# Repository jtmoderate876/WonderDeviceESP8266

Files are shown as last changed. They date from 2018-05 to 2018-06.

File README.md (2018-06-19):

# WonderDeviceESP8266

The device can be reset using #   DoubleResetDetect by Jens-Christian Skibakk

You can then configure via wifimanager by connecting to the ESPXXXXXX device and setting your SSID/PWD/ETC.

Raspberry pi's set up for Wonderware ITME "IoTView" per the following:

```
#install apache on pi:
sudo apt-get install apache2
#sudo systemctl disable apache2
#sudo systemctl stop apache2
#sudo systemctl restart apache2
sudo systemctl start apache2
sudo systemctl enable apache2
#skip the old service way which still works:
#sudo service apache2 start
#sudo service apache2 restart
#enable cgi
sudo a2enmod cgi
sudo cp /etc/apache2/mods-available/cgi.load /etc/apache2/mods-enabled/
```

Now from a windows pc that has Wonderware ITME installed copy the remote agent files from PC to removable drive:
copy "C:\Program Files (x86)\Wonderware\InTouch Machine Edition v8.1\Redist\IoTView\Linux\arm-gnueabihf-2.13-6.0.17\*.*"
"d:\iotview\*.*"

```
# now on raspberry create a directory and copy those:

md /home/pi/iotview
cd /home/pi/iotview
cp /media/pi/LexarNTFS/iotview /home/pi/iotview
#or sudo pcmanfm
sudo ./install.sh -a -i

#copy iotview cgi to apache cgi-bin
sudo cp webaddon/CGI/WebCGIProc /usr/lib/cgi-bin/WebCGIProc
sudo systemctl disable remote-agent
sudo service remote-agent start
  144  ls
  145  cd iotview
  146  ls
  147  sudo cp webaddon/CGI/WebCGIProc /usr/lib/cgi-bin/WebCGIProc
  148  sudo chmod a+x /usr/lib/cgi-bin/WebCGIProc
  149  sudo ln -s MA /var/www/MA
  150  service apache2 restart
  151  nano /var/www/MA/sma/config.js
  152  sudo nano /var/www/MA/sma/config.js

```

If you already have a raspberry pi (2, 3 or maybe even a zero - I haven't tried IoTView with the slower processor in pizerow) then you can skip buying the pi stuff otherwise you may look at parts such as these:
Raspberry Pi Complete:
http://a.co/gGVRZKB

You can run any MQTT Broker (mosquitto, node-red, or perhaps others)

On a PC install the Wonderware ITME Development environment (demo mode available from your Wonderware guy or downloadable from
wdn.wonderware.com with a support account).
We use it to create the HMI and download it to the pi.

To skip the pi and use just the PC you can install an mqtt broker on your PC (again, either mosquitto or several others are available for PC) and use it with Wonderware InTouch or ITME or System Platform.

The WonderDevicESP8266 Sensor:
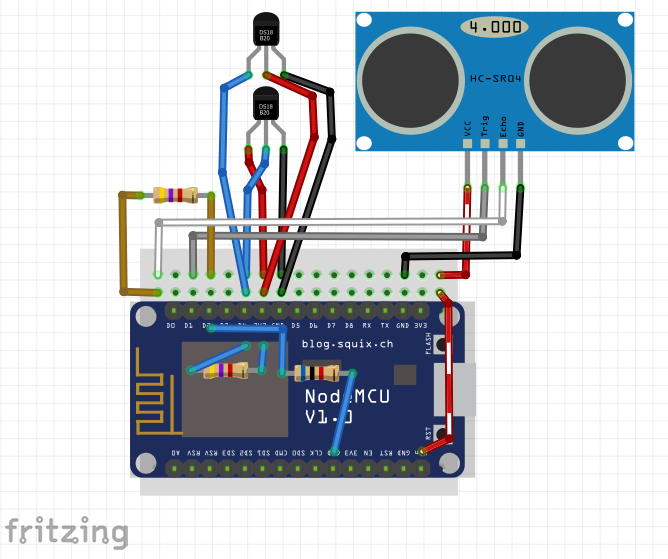
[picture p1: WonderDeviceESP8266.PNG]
Wiring up WonderDeviceESP8266.


We went with an ESP8266 12E microcontroller (also known as NodeMCU), 2 temperature probes and an ultrasonic distance sensor.

These are programmed with the arduino IDE - which can be installed on either a PC or your Raspberry PI.
If you use Arduino  on pi, don't use the standard installation (sudo apt-get install arudino) because that is an old version that doesn't support other boards like the ESP8266. Instead install via:

```
# on pi in Chromium browser navigate to https://www.arduino.cc/en/Main/Software and download for linux arm
# extract in place by right clicking using:
pcmanfm
cd /home/pi/Downloads/arduino-1.8.5
sudo mv /home/pi/Downloads/arduino-1.8.5 /opt/arduino-1.8.5
cd /opt/arduino-1.8.5
./install.sh

# now you need to add esp8266/nodemcu support to arduino ide
# run arduino (Start>Programming>Arduino) and menu: edit > preferences ...paste the following in "Additional Boards Manager":
http://arduino.esp8266.com/stable/package_esp8266com_index.json
# restart arduino ide and Tools > Board > Boards Manager and "Install" esp8266
# >Sketch>Include Libraries>Manage Libraries ... add:
#   PubSubClient from Nick O'Leary
#   OneWire by  Jim Studt, etc.
#   DallasTemperature by Miles Burton, etc.
#   WifiManager by Tzapu
#   ArduinoJson by Benoit Blanchon
#   DoubleResetDetect by Jens-Christian Skibakk
#   
```

The untrasonic sensor is called HC-SR04 BUT...
Rather than having to create / wire a voltage divider to know the 5V down to 3.3v it is much better to find an HC-SR04 that works with 3V.
Our first were the common, 5VDC type - which required us to create a voltage divider using several additional resistors - which was a pain.

Get 3v-5v version (a little harder to find - sometimes called  "wide voltage range" or "Upgraded voltage") which match the inputs on the ESP8266 microcontroller and doesn't require the extra two resistors and wiring.

Unfortunately they are all called HC-SR04 so you need to check that it is 3V tolerant.

I've created a list of materials on Amazon
WonderDeviceESP8266 example BOM: http://a.co/bolUVeg

Anything you have already laying around (like a MicroUSB cable, USB Power, wires, etc.) you wouldn't need to buy.
If you are patient with shipping then you can find this stuff cheaper (sometimes MUCH CHEAPER) at https://www.aliexpress.com/

A wiring diagram (the PNG file) can be found here too:
  https://github.com/jtmoderate876/WonderDeviceESP8266

Misc. supplies such as screw driver, wire cutter, hot glue gun, soldering iron and solder (the temperature probes have flimsy wires that can't be pressed into the breadboard so we cut some of those Dupont wires and soldered them to it), band-aids :), etc.

The program in the ESP device uses:
 https://github.com/tzapu/WiFiManager
and
 https://github.com/jenscski/DoubleResetDetect
So when it first boots, or whenever a double-reset is detected, WebServer (default ip 192.168.4.1)

For the time being I have a raspberry pi image with a sample application on the desktop for v8.1+ Wonderware InTouch Machine Edition IoTView / InduSoft WebStudio IoTView (pi/raspberry):
https://1drv.ms/f/s!AvJzcfwnK1a3g61JaO3n66KUUUTJbw

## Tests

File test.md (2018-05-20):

testing
1
2
3
4

new lines
should be 
often

new
line

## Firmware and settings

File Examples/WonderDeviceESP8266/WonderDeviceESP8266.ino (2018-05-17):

#include <FS.h>                   //this needs to be first, or it all crashes and burns...
//will eventually store things here:
// https://github.com/jtmoderate876/WonderDeviceESP8266

#include <DoubleResetDetect.h>  //https://github.com/jenscski/DoubleResetDetect
#define DRD_TIMEOUT 2.0         // max seconds between resets for double reset
#define DRD_ADDRESS 0x00        // address of block of RTC user memory, may need to change it if it collides with another usage 
DoubleResetDetect drd(DRD_TIMEOUT, DRD_ADDRESS);

#include <ESP8266WiFi.h>          //https://github.com/esp8266/Arduino

//needed for library
#include <DNSServer.h>
#include <ESP8266WebServer.h>
#include <WiFiManager.h>          //https://github.com/tzapu/WiFiManager

#include <ArduinoJson.h>          //https://github.com/bblanchon/ArduinoJson

//define your default values here, if there are different values in config.json, they are overwritten.
char mqtt_server[40] = "172.20.10.2";
char mqtt_port[6] = "1883";
char device_name[40] ;
char ultrarollovercountchar[7] ="1000";
char ultracountermaxdistancechar[4] = "30";
char topictemp[60];
/*
will automatically create:
 ./temperature/0/pv
 ./temperature/1/pv
 ./temperature/delta/pv
 ./distance/pv
 ./count/pv
*/
long  ultrarollovercount = 1000;
long  ultracountermaxdistance= 30; //30 cm or closer constitutes an object passing
char hiername_t0[60]        =  "temperature/0/pv";
char hiername_t1[60]        =  "temperature/1/pv";
char hiername_dt[60]        =  "temperature/delta/pv";//dt=t0-t1
char hiername_distance[60]  =  "distance/pv";// distance in cm
char hiername_count[60]     =  "count/pv";// 999 rollover counter (passing parts, people

String autoconf_apssid; // name of this device when used as accesspoint (during configuration)

//flag for saving data
bool shouldSaveConfig = false;

#include <ESP8266WiFi.h>
#include <PubSubClient.h>

# 
long ultradistancelastMsg = 0;


WiFiClient espClient;
PubSubClient client(espClient);
long temperatureslastMsg = 0;
char msg[50];
int value = 0;

long now; //will contain milliseconds

//dallas onewire two temperature 
char temp0Fchar[6];
float temp0F = -999;
char temp1Fchar[6];
float temp1F = -999;
float difftemp0minus1F = -999;
char difftemp0minus1Fchar[6];
char prevtemp0Fchar[6];
char prevtemp1Fchar[6];
int ret = 0;
bool temperaturesupdaterequiredflag = false;
// Include the libraries we need

#include <OneWire.h>
#include <DallasTemperature.h>
// Data wire is plugged into port 2 on the Arduino
#define ONE_WIRE_BUS 2
#define TEMPERATURE_PRECISION 12 // 9=0.9F, 10=0.45F, 11=0.225F, 12=0.1122F (.5C,.25C,.125c,.0625C)
// Setup a oneWire instance to communicate with any OneWire devices (not just Maxim/Dallas temperature ICs)
OneWire oneWire(ONE_WIRE_BUS);
// Pass our oneWire reference to Dallas Temperature. 
DallasTemperature sensors(&oneWire);
//float prevtempF = -999;
// arrays to hold device addresses
DeviceAddress thermometer0, thermometer1;

//ultrasonic distance and rollover counter
#define ultratrigPin 5
#define ultraechoPin 4
int ultracounter = 0;
int ultracurrentState = 0;
int ultrapreviousState = 0;
long ultraduration, ultradistance;
long ultrapreviousdistance = 0;
long ultradistancediff = 0;
bool ultraupdaterequiredflag = false;
char ultracounterchar[6];
char ultradistancechar[6];


//callback notifying us of the need to save config
void saveConfigCallback () {
  Serial.println("Should save config");
  shouldSaveConfig = true;
}

void setup() {
  // put your setup code here, to run once:
  Serial.begin(115200);
  Serial.println();//new line to clear noise/garbage

  //WiFiManager
  //Local intialization. Once its business is done, there is no need to keep it around
  WiFiManager wifiManager;

  if (drd.detect()) {
    Serial.println("** Double reset boot - resetting wifimanager settings. Pay no attention to the next 3 lines (settings invalidated, THIS MAY..., and new line) from wifimanager:**");
    wifiManager.resetSettings();  //reset settings - for testing
    //do we want to do something with ??: 
    //clean FS, for testing
    SPIFFS.format();
  } else {
    Serial.println("** Normal boot **");
  }
  //clean FS, for testing
  //wifiManager.resetSettings();  //reset settings - for testing
  //SPIFFS.format();


  //read configuration from FS json
  Serial.println("mounting FS...");

  if (SPIFFS.begin()) {
    Serial.println("mounted file system");
    if (SPIFFS.exists("/config.json")) {
      //file exists, reading and loading
      Serial.println("reading config file");
      File configFile = SPIFFS.open("/config.json", "r");
      if (configFile) {
        Serial.println("opened config file");
        size_t size = configFile.size();
        // Allocate a buffer to store contents of the file.
        std::unique_ptr<char[]> buf(new char[size]);

        configFile.readBytes(buf.get(), size);
        DynamicJsonBuffer jsonBuffer;
        JsonObject& json = jsonBuffer.parseObject(buf.get());
        json.printTo(Serial);
        if (json.success()) {
          Serial.println("\nparsed json");

          strcpy(mqtt_server, json["mqtt_server"]);
          strcpy(mqtt_port, json["mqtt_port"]);
//          strcpy(blynk_token, json["blynk_token"]);

        } else {
          Serial.println("failed to load json config");
        }
      }
    }
  } else {
    Serial.println("failed to mount FS");
  }
  //end read



  autoconf_apssid = "ESP"+String(ESP.getChipId());//create a default device id of the form ESP plus the Chip ID
  strcpy(device_name, autoconf_apssid.c_str()); //also store it as devicename
  
  // The extra parameters to be configured (can be either global or just in the setup)
  // After connecting, parameter.getValue() will get you the configured value
  // id/name placeholder/prompt default length
  // WiFiManagerParameter custom_parameter( ID in wifi mgr, prompt, default value, max length);
  WiFiManagerParameter custom_mqtt_server("server", "mqtt server", mqtt_server, 40);
  WiFiManagerParameter custom_mqtt_port("port", "mqtt port", mqtt_port, 6);
  WiFiManagerParameter custom_device_name("topic", "mqtt base topic", device_name, 40);
  WiFiManagerParameter custom_counter_rollover("counterrollover", "counter rollover value", ultrarollovercountchar, 7);
  WiFiManagerParameter custom_counter_maxdist("countermaxdist", "max distance to count", ultracountermaxdistancechar, 4);
//  WiFiManagerParameter custom_blynk_token("blynk", "blynk token", blynk_token, 32);


  //set config save notify callback
  wifiManager.setSaveConfigCallback(saveConfigCallback);

  //set static ip
//  wifiManager.setSTAStaticIPConfig(IPAddress(10,0,1,99), IPAddress(10,0,1,1), IPAddress(255,255,255,0));
  
  //add all your parameters here
  wifiManager.addParameter(&custom_mqtt_server);
  wifiManager.addParameter(&custom_mqtt_port);
  wifiManager.addParameter(&custom_device_name);
  wifiManager.addParameter(&custom_counter_rollover);
  wifiManager.addParameter(&custom_counter_maxdist);
//  wifiManager.addParameter(&custom_blynk_token);

  //reset settings - for testing
  //wifiManager.resetSettings();

  //set minimu quality of signal so it ignores AP's under that quality
  //defaults to 8%
  //wifiManager.setMinimumSignalQuality();
  
  //sets timeout until configuration portal gets turned off
  //useful to make it all retry or go to sleep
  //in seconds
  //wifiManager.setTimeout(120);

  //fetches ssid and pass and tries to connect
  //if it does not connect it starts an access point with the specified name
  //here  "AutoConnectAP"
  //and goes into a blocking loop awaiting configuration
//  if (!wifiManager.autoConnect("AutoConnectAP", "password")) {
//  if (!wifiManager.autoConnect()) {
  if (!wifiManager.autoConnect(autoconf_apssid.c_str())) {
    Serial.println("failed to connect and hit timeout");
    delay(3000);
    //reset and try again, or maybe put it to deep sleep
    ESP.reset();
    delay(5000);
  }

  //if you get here you have connected to the WiFi
  Serial.println("connected...yeey :)");

  //read updated parameters
  strcpy(mqtt_server, custom_mqtt_server.getValue());
  strcpy(mqtt_port, custom_mqtt_port.getValue());
  strcpy(device_name, custom_device_name.getValue());
  strcpy(ultrarollovercountchar, custom_counter_rollover.getValue());
  strcpy(ultracountermaxdistancechar, custom_counter_maxdist.getValue());
//  strcpy(blynk_token, custom_blynk_token.getValue());

  //save the custom parameters to FS
  if (shouldSaveConfig) {
    Serial.println("saving config");
    DynamicJsonBuffer jsonBuffer;
    JsonObject& json = jsonBuffer.createObject();
    json["mqtt_server"] = mqtt_server;
    json["mqtt_port"] = mqtt_port;
    json["device_name"] = device_name;
    json["ultrarollovercountchar"] = ultrarollovercountchar;
    json["ultracountermaxdistancechar"] = ultracountermaxdistancechar;
//    json["blynk_token"] = blynk_token;

    File configFile = SPIFFS.open("/config.json", "w");
    if (!configFile) {
      Serial.println("failed to open config file for writing");
    }

    json.printTo(Serial);
    json.printTo(configFile);
    configFile.close();
    //end save
  }

//  Serial.println("local ip");
//  Serial.println(WiFi.localIP());

  ultrarollovercount = atoi(ultrarollovercountchar);
  ultracountermaxdistance = atoi(ultracountermaxdistancechar);
  Serial.print("ultrarollovercount = ");
  Serial.print(ultrarollovercount);
  Serial.print(" converted from ultrarollovercountchar = ");
  Serial.print(ultrarollovercountchar);
  Serial.print(" and ultracountermaxdistancechar = ");
  Serial.print(ultracountermaxdistancechar);
  Serial.print(" converted to = ");
  Serial.print(ultracountermaxdistance);
  Serial.println();



  // requestTemperatures() will not block current thread
  sensors.setWaitForConversion(false);

  pinMode(BUILTIN_LED, OUTPUT);     // Initialize the BUILTIN_LED pin as an output
//  setup_wifi();
  client.setServer(mqtt_server, atoi(mqtt_port));
//  client.setCallback(callback);

  // Start up the library (dallas)
  sensors.begin();

    // locate devices on the bus
  Serial.print("Locating devices...");
  Serial.print("Found ");
  Serial.print(sensors.getDeviceCount(), DEC);
  Serial.println(" devices.");

  // report parasite power requirements
  Serial.print("Parasite power is: ");
  if (sensors.isParasitePowerMode()) Serial.println("ON");
  else Serial.println("OFF");

  if (!sensors.getAddress(thermometer0, 0)) Serial.println("Unable to find address for Device thermometer0");
  if (!sensors.getAddress(thermometer1, 1)) Serial.println("Unable to find address for Device thermometer1");

  // show the addresses we found on the bus
  Serial.print("Device 0 Address: ");
  printAddress(thermometer0);
  Serial.println();

  Serial.print("Device 1 Address: ");
  printAddress(thermometer1);
  Serial.println();

  // set the resolution to 9 bit per device
  sensors.setResolution(thermometer0, TEMPERATURE_PRECISION);
  sensors.setResolution(thermometer1, TEMPERATURE_PRECISION);

  Serial.print("Device 0 Resolution: ");
  Serial.print(sensors.getResolution(thermometer0), DEC);
  Serial.println();

  Serial.print("Device 1 Resolution: ");
  Serial.print(sensors.getResolution(thermometer1), DEC);
  Serial.println();

  //ultrasonic distance and rollover counter
  pinMode(ultratrigPin, OUTPUT);
  pinMode(ultraechoPin, INPUT);

   //add devicename and "/" to front of all the topics
   char tempchar[60];
  sprintf(tempchar, "%s/%s", device_name, hiername_t0);
  strcpy(hiername_t0, tempchar);
  sprintf(tempchar, "%s/%s", device_name, hiername_t1);
  strcpy(hiername_t1, tempchar);
  sprintf(tempchar, "%s/%s", device_name, hiername_dt);
  strcpy(hiername_dt, tempchar);
  sprintf(tempchar, "%s/%s", device_name, hiername_distance);  // distance in cm
  strcpy(hiername_distance, tempchar);
  sprintf(tempchar, "%s/%s", device_name, hiername_count);        // 999 rollover counter (passing parts, people...)
  strcpy(hiername_count, tempchar);
  Serial.print("For example, hiername_count=" );
  Serial.println(hiername_count);
}

//mqtt
void reconnect() {
  // Loop until we're reconnected
  while (!client.connected()) {
    Serial.print("Attempting MQTT connection...");
    // Create a random client ID
    String clientId = "ESP8266Client-";
    clientId += String(random(0xffff), HEX);
    // Attempt to connect
    if (client.connect(clientId.c_str())) {
      Serial.println("connected");
      // Once connected, publish an announcement...
      client.publish("outTopic", "hello world");
      // ... and resubscribe
      client.subscribe("inTopic");
    } else {
      Serial.print("failed, rc=");
      Serial.print(client.state());
      Serial.println(" try again in 5 seconds");
      // Wait 5 seconds before retrying
      delay(5000);
    }
  }
}

// more dallas functions
// dallas function to print a device address
void printAddress(DeviceAddress deviceAddress)
{
  for (uint8_t i = 0; i < 8; i++)
  {
    // zero pad the address if necessary
    if (deviceAddress[i] < 16) Serial.print("0");
    Serial.print(deviceAddress[i], HEX);
  }
}

// dallas function to print the temperature for a device
void printTemperature(DeviceAddress deviceAddress)
{
  float tempC = sensors.getTempC(deviceAddress);
  Serial.print("Temp C: ");
  Serial.print(tempC);
  Serial.print(" Temp F: ");
  Serial.print(DallasTemperature::toFahrenheit(tempC));
}

// dallas function to print a device's resolution
void printResolution(DeviceAddress deviceAddress)
{
  Serial.print("Resolution: ");
  Serial.print(sensors.getResolution(deviceAddress));
  Serial.println();
}

// dallas main function to print information about a device
void printData(DeviceAddress deviceAddress)
{
  Serial.print("Device Address: ");
  printAddress(deviceAddress);
  Serial.print(" ");
  printTemperature(deviceAddress);
  Serial.println();
}




void loop() {
  // put your main code here, to run repeatedly:
  if (!client.connected()) {
    reconnect();
  }
  client.loop();

  now = millis();

//  Serial.print(now);   Serial.print(" ");  Serial.print(temperaturesupdaterequiredflag);  Serial.print(" ");  Serial.print(temperatureslastMsg);  Serial.print(" ");
  
  temperaturesupdaterequiredflag = false;
  if (now - temperatureslastMsg > 2000) {
    temperatureslastMsg = now;
  
    // Fetch temperatures from Dallas sensors
    // call sensors.requestTemperatures() to issue a global temperature 
    // request to all devices on the bus
    //Serial.print("Requesting temperatures...");
    sensors.requestTemperatures(); // Send the command to get temperatures
   
    // After we got the temperatures, we can print them here.
    // We use the function ByIndex, and as an example get the temperature from the first sensor only.
    temp0F = sensors.getTempFByIndex(0);
    temp0F = roundf(temp0F*10)/10; // 0.1 deg F precision
    ret = snprintf(temp0Fchar,sizeof temp0Fchar, "%.1f", temp0F);
    client.publish(hiername_t0, temp0Fchar);

    temp1F = sensors.getTempFByIndex(1);
    temp1F = roundf(temp1F*10)/10; // 0.1 deg F precision
    ret = snprintf(temp1Fchar,sizeof temp1Fchar, "%.1f", temp1F);
    client.publish(hiername_t1, temp1Fchar);

    difftemp0minus1F = temp0F - temp1F;
//    difftemp0minus1F = roundf(difftemp0minus1F *10)/10; // 0.1 deg F precision
    ret = snprintf(difftemp0minus1Fchar,sizeof difftemp0minus1Fchar, "%.1f", difftemp0minus1F);
    client.publish(hiername_dt, difftemp0minus1Fchar);
    
    // for serial print only print if there is change
    if (prevtemp0Fchar!=temp0Fchar) {
      strcpy(prevtemp0Fchar, temp0Fchar);
      temperaturesupdaterequiredflag = true;
    }
    if (prevtemp1Fchar!=temp1Fchar) {
      strcpy(prevtemp1Fchar, temp1Fchar);
      temperaturesupdaterequiredflag = true;
    }
  }

  //ultrasonic
  ultraupdaterequiredflag = false;
  if (now - ultradistancelastMsg > 100) {
//    Serial.print(" inside ultra with time of ");
//    Serial.print(ultradistancelastMsg );
    ultradistancelastMsg = now;
//    ultracountlastMsg = 0;

    digitalWrite(ultratrigPin, LOW); 
    delayMicroseconds(2); 
    digitalWrite(ultratrigPin, HIGH);
    delayMicroseconds(10); 
    digitalWrite(ultratrigPin, LOW);
    ultraduration = pulseIn(ultraechoPin, HIGH);
    ultradistance = (ultraduration/2) / 29.1;
  
    ultradistancediff = ultrapreviousdistance - ultradistance;
    if (abs(ultradistancediff)>1) {
      ultrapreviousdistance = ultradistance;
      ultraupdaterequiredflag = true;
      sprintf(ultradistancechar , "%d", ultradistance);
//      sprintf(ultradistancechar , "%04d", ultradistance);
      client.publish(hiername_distance , ultradistancechar);
    }

    if (ultradistance <= ultracountermaxdistance){
      ultracurrentState = 1;
    }
    else {
      ultracurrentState = 0;
    }
    if(ultracurrentState != ultrapreviousState){
      if(ultracurrentState == 1){
        ultracounter = ultracounter + 1;
        if (ultracounter > ultrarollovercount ) {
          ultracounter = ultracounter - ultrarollovercount;      
        }
        ultraupdaterequiredflag = true;
        ultracounterchar;
        sprintf(ultracounterchar, "%d", ultracounter);
        client.publish(hiername_count , ultracounterchar);
      }
    }
    ultrapreviousState = ultracurrentState;
  }


  //Serial.print if needed
  if ( ultraupdaterequiredflag | temperaturesupdaterequiredflag) {
    Serial.print("Counter: ");  
//    Serial.print(ultracounter); 
    Serial.print(  ultracounter/100 );
    Serial.print((ultracounter/10)%10);
    Serial.print(ultracounter%10);
    Serial.print(" Distance: ");
    Serial.print(ultradistance );
    Serial.print(" cm");  

    Serial.print("   Temps in deg F: Temp0: ");
    Serial.print(temp0Fchar);
    Serial.print(" and Temp1: ");
    Serial.print(temp1Fchar);
    Serial.print(" and t0-t1: ");
    Serial.print(difftemp0minus1Fchar);

    Serial.println();
  }


}

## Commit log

2018-05-17 Initial commit of ESP8266 INO files for both device operation and to wipe SPIFFS/WIFIManager Signed-off-by: Jeff Tapia <jeff.tapia@live.com>
2018-05-18 Added fritzing wiring diagram source file via upload
    Filename WonderDevice ESP8266 2 temp and dist and counter.fzz
    [WonderDevice ESP8266 2 temp and dist and counter.fzz]
2018-05-18 added note about 3volt tolerant ultrasonic HC-SR04 Signed-off-by: Jeff Tapia <jeff.tapia@live.com>
    [WonderDevice ESP8266 2 temp and dist and counter.fzz]
2018-05-30 added wiring png to readme.dm
2018-06-15 added link to raspberry pi image
